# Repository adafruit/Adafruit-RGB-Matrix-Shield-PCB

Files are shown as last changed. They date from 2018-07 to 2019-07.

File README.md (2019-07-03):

## Adafruit RGB Matrix Display Shield PCB

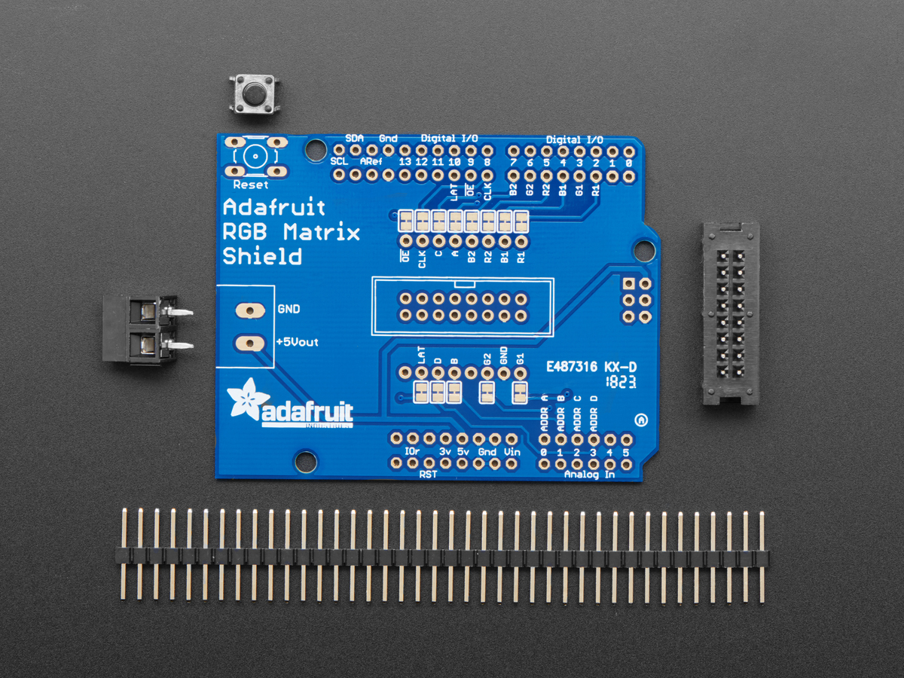
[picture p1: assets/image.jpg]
<a href="http://www.adafruit.com/products/2601"><br/>
Click here to purchase one from the Adafruit shop</a>

PCB files for the Adafruit RGB Matrix Shield. PCB format is EagleCAD schematic and board layout

For more details, check out the product page at
* https://www.adafruit.com/product/2601

### Description

Our RGB matricies are dazzling, with their hundreds or even thousands of individual RGB LEDs. Compared to NeoPixels, they've got great density, power usage and the price-per-LED can't be beat. But...(isn't there always a but?) You need to use our special library to control them and they require a bunch of wires to be plugged in. Tougher than a single-wire connection for sure.

If you've got an Arduino-compatible board, with an ATmega328p chip (like our Metro 328) or SAMD21 (like the Metro M0) or even SAMD51 (like our Metro M4) this shield will make usage a snap! A little light soldering to attach the headers, connector and terminal block and you're ready to rock. Plug it onto your microcontroller board, and you'll be able to attach any RGB matrix with ease. This shield just takes care of the wiring for you!

For 800mA or less power usage on the matrix you can even 'borrow' the 5V power from the Arduino's regulator. This isn't good for projects where you have a lot of LEDs on at once but for scrolling text and light LED usage it will make wiring even easier because you dont need a separate power adapter. Of course, if you need 1 Amp or more, just use the 2x8 connector for data and use a separate 5V 2A or 5V 4A wall adapter directly to the panel.

Note that this shield is just a wiring adapter, if you have a Metro 328 you can only use 16x32 or possibly 32x32 matrices before you run out of RAM. For big panels, use a Metro M0 or M4 - those will work best thanks to their enormous RAM.

**Please note our Arduino library only supports 32-pixel tall matrices, so don't try using a 64x64 matrix, it doesn't work!**

### License

Adafruit invests time and resources providing this open source design, please support Adafruit and open-source hardware by purchasing products from [Adafruit](https://www.adafruit.com)!

Designed by Limor Fried/Ladyada for Adafruit Industries.

Creative Commons Attribution/Share-Alike, all text above must be included in any redistribution. See license.txt for additional details.

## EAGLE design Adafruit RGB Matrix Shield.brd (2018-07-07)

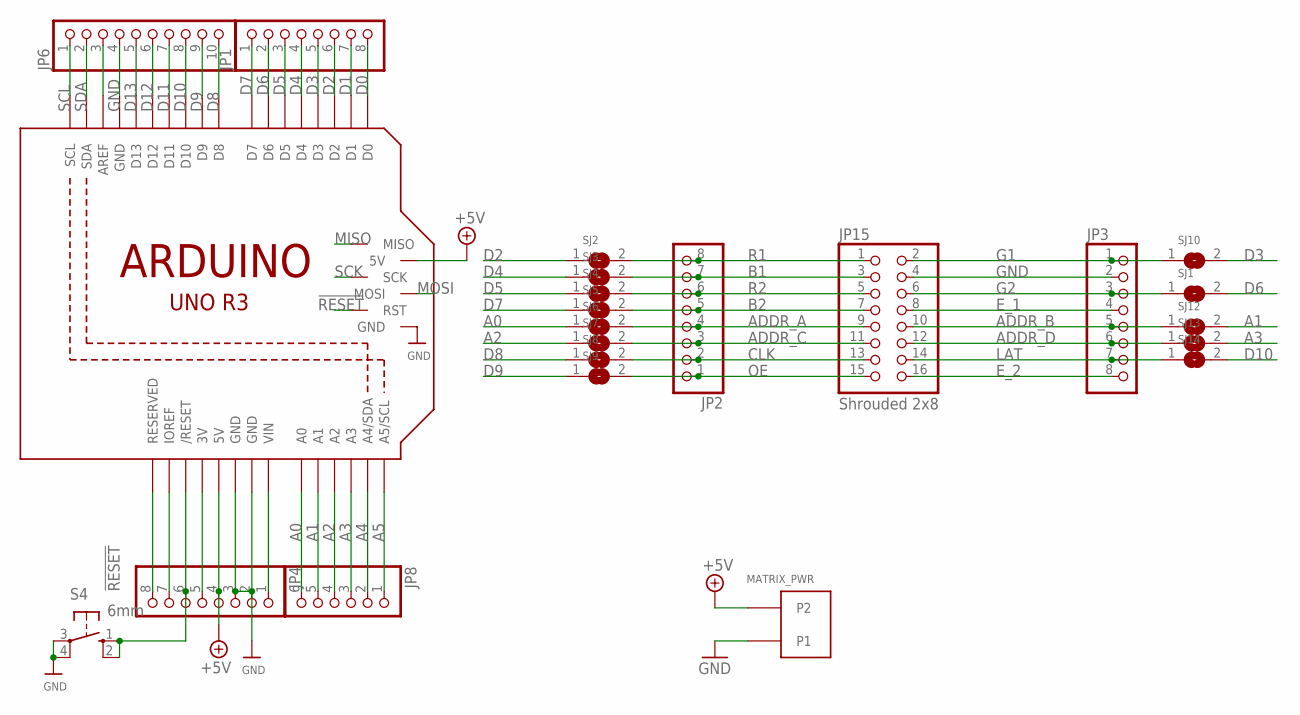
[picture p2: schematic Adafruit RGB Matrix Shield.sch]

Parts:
JP1, JP4: PINHD-1X8CLEANBIG; 1X08-CLEANBIG
JP2, JP3: HEADER-1X876MIL; 1X08_ROUND_76
JP6: HEADER-1X1070MIL; 1X10_ROUND70
JP8: PINHD-1X6CB; 1X06-CLEANBIG
JP15: Shrouded 2x8; 2X08_SHROUDED
MATRIX_PWR: PINHEAD; TERMBLOCK508
S4: 6mm; B3F-10XX
SJ1, SJ2, SJ3, SJ4, SJ5, SJ6, SJ7, SJ8, SJ9, SJ10, SJ12, SJ13, SJ14: SOLDERJUMPERCLOSED; SOLDERJUMPER_CLOSEDWIRE
U$41: ARDUINO_R3_ICSP_NODIM; ARDUINOR3_ICSP_NODIM

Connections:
!RESET: JP4.6, S4.1 (S), S4.2 (S1), U$41.RESET (/RESET), U$41.RESET_ICSP (RST)
+3V: JP4.5, U$41.3V
+5V: JP4.4, MATRIX_PWR.P$4 (P2), U$41.5V, U$41.5V_ICSP (5V)
A0: JP8.6, SJ6.1, U$41.A0
A1: JP8.5, SJ12.2, U$41.A1
A2: JP8.4, SJ7.1, U$41.A2
A3: JP8.3, SJ13.2, U$41.A3
A4: JP8.2, U$41.A4 (A4/SDA)
A5: JP8.1, U$41.A5 (A5/SCL)
ADDR_A: JP2.4, JP15.9, SJ6.2
ADDR_B: JP3.5, JP15.10, SJ12.1
ADDR_C: JP2.3, JP15.11, SJ7.2
ADDR_D: JP3.6, JP15.12, SJ13.1
AREF: JP6.3, U$41.AREF
B1: JP2.7, JP15.3, SJ3.2
B2: JP2.5, JP15.7, SJ5.2
CLK: JP2.2, JP15.13, SJ8.2
D0: JP1.8, U$41.D0
D1: JP1.7, U$41.D1
D2: JP1.6, SJ2.1, U$41.D2
D3: JP1.5, SJ10.2, U$41.D3
D4: JP1.4, SJ3.1, U$41.D4
D5: JP1.3, SJ4.1, U$41.D5
D6: JP1.2, SJ1.2, U$41.D6
D7: JP1.1, SJ5.1, U$41.D7
D8: JP6.10, SJ8.1, U$41.D8
D9: JP6.9, SJ9.1, U$41.D9
D10: JP6.8, SJ14.2, U$41.D10
D11: JP6.7, U$41.D11
D12: JP6.6, U$41.D12
D13: JP6.5, U$41.D13
E_1: JP3.4, JP15.8
E_2: JP3.8, JP15.16
G1: JP3.1, JP15.2, SJ10.1
G2: JP3.3, JP15.6, SJ1.1
GND: JP3.2, JP4.2, JP4.3, JP6.4, JP15.4, MATRIX_PWR.P$3 (P1), S4.3, S4.4 (P1), U$41.GND, U$41.GND@1 (GND), U$41.GND@2 (GND), U$41.GND@3 (GND)
IOREF: JP4.7, U$41.IOREF
LAT: JP3.7, JP15.14, SJ14.1
MISO: U$41.MISO
MOSI: U$41.MOSI
NC: JP4.8, U$41.RESERVED
OE: JP2.1, JP15.15, SJ9.2
R1: JP2.8, JP15.1, SJ2.2
R2: JP2.6, JP15.5, SJ4.2
SCK: U$41.SCK
SCL: JP6.1, U$41.SCL
SDA: JP6.2, U$41.SDA
VIN: JP4.1, U$41.VIN

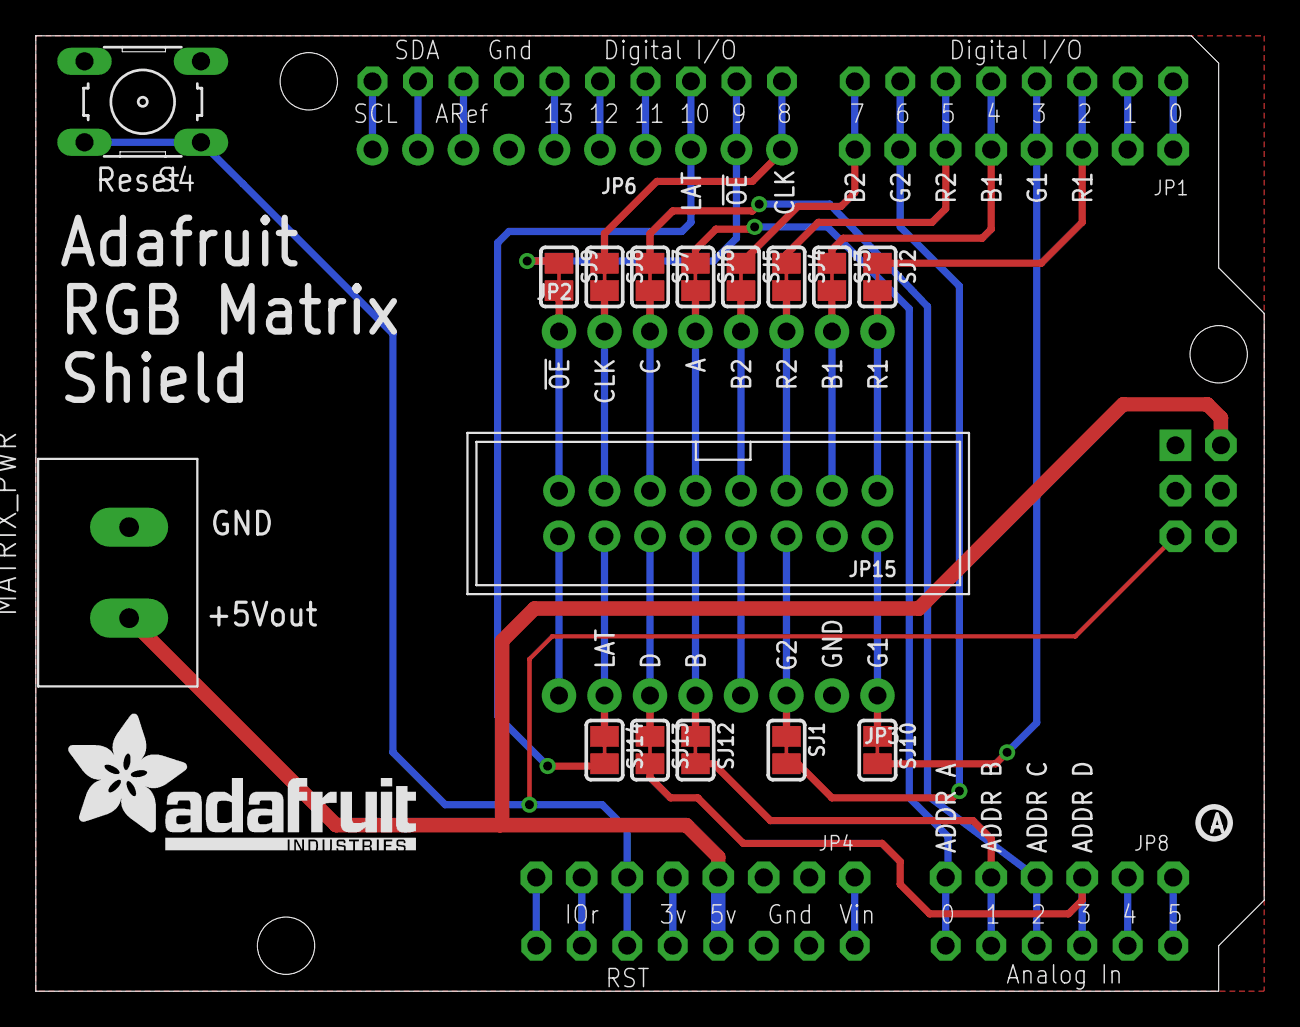
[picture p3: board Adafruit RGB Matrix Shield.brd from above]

Board: 2 copper layers, 68.6 x 53.3 mm, 25 parts (0 on the bottom side), 45 nets.

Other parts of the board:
U$8: PCBFEAT-REV-040
U$9: ADAFRUIT_TEXT_20MM
